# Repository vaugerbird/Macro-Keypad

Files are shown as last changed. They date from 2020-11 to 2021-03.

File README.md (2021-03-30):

# Macro-Keypad
Designed by vaugerbird

Features
---------

* Features 6 programable macro keys
* Controlled by ATMega32u4 that can be flashed with Arduino bootloader
* Uses a USB Type C connector at USB 2.0 speeds
* Updated Pro Micro board is also included (great for beginners)

Notes
------

All of the mechanical key switches are all programed in EAGLE as Cherry MX keys or equivalent footprint

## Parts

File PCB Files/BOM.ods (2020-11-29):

Part Description | Part # | Mouser # | Digikey # | Footprint | $/Unit | Qty # | Board ID # | Mouser Link | Digikey Link | Notes
ATMega32u4 | ATMEGA32U4-MU | 556-ATMEGA32U4-MU | ATMEGA32U4-AURCT-ND | QFN-44 | $3.98 | 1 | N/A | Mouser (https://www.mouser.com/ProductDetail/Microchip-Technology-Atmel/ATMEGA32U4-MU?qs=JV7lzlMm3yJYRpi0cY3cKw%3D%3D) | Digikey (https://www.digikey.com/en/products/detail/microchip-technology/ATMEGA32U4-AUR/2238241) | Had to change from AU to MU to fit PCB
USB C Port | USB4085-GF-A | N/A | 2073-USB4085-GF-ACT-ND | N/A | $1.34 | 1 | USB-C | N/A | Digikey (https://www.digikey.com/en/products/detail/gct/USB4085-GF-A/9859662) | Current footprint incorrect, getting fixed.
5.1k Pull-Down Resistor | CRCW06035K10KKEATR | 71-CRCW06035K10KKEAT | SR0603KR-075K1L-ND | 0603 | $0.37 | 1 | R1 | Mouser (https://www.mouser.com/ProductDetail/Vishay-Dale/CRCW06035K10KKEATR?qs=V3IlGBufnyVplw9ReaVc8A%3D%3D) | Digikey (https://www.digikey.com/en/products/detail/yageo/SR0603KR-075K1L/5948489) | Minimum order of 5000 from Digi
22 Ohm Data Resistor | RS73G2ATTD22R0B | 660-RS73G2ATTD22R0B | 2019-RS73G2ATTD22R0BTR-ND | 0805 | $0.52 | 2 | R2, R3 | Mouser (https://www.mouser.com/ProductDetail/KOA-Speer/RS73G2ATTD22R0B?qs=YwPsRIUVAOdxbc5%2F8NI5WA%3D%3D) | Digikey (https://www.digikey.com/en/products/detail/koa-speer-electronics-inc/RS73G2ATTD22R0B/11573620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) | Minimum order of 5000 from Digi
1uF Capacitor | C0805C105M5PACTU | 80-C0805C105M5P | N/A | 0805 | $0.76 | 1 | C1 | Mouser (https://www.mouser.com/ProductDetail/KEMET/C0805C105M5PACTU?qs=Mv1qlCsH0%252BHK4n8YpZMO7w%3D%3D) | N/A
Push Button Reset Switch | LL3303F065QG | 612-LL3303F065QG | LL3303F065QG-ND | N/A | $0.60 | 1 | RESET | Mouser (https://www.mouser.com/ProductDetail/E-Switch/LL3303F065QG?qs=QtyuwXswaQjocAyEnLyPSg%3D%3D) | Digikey (https://www.digikey.com/en/products/detail/e-switch/LL3303F065QG/4028397) | Minimum order of 7500 from Digi

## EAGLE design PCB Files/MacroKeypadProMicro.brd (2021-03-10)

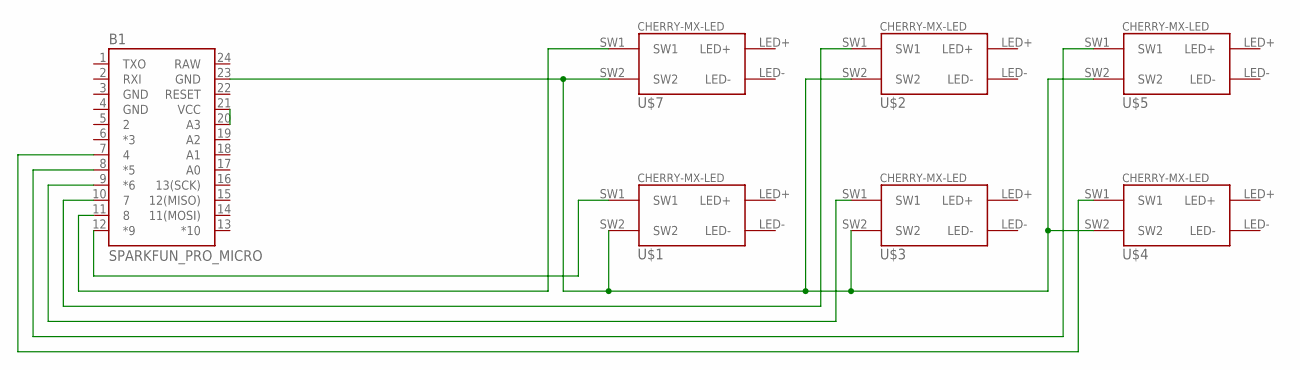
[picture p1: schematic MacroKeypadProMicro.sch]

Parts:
B1: SPARKFUN_PRO_MICRO
U$1, U$2, U$3, U$4, U$5, U$7: CHERRY-MX-LED

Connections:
GND: B1.3 (GND), B1.4 (GND), B1.23 (GND), U$1.SW2, U$2.SW2, U$3.SW2, U$4.SW2, U$5.SW2, U$7.SW2
unnamed: B1.20 (A3), B1.21 (VCC)
RAW: B1.24 (RAW)
SW1: B1.11 (8), U$7.SW1
SW2: B1.9 (*6), U$3.SW1
SW3: B1.7 (4), U$4.SW1
SW4: B1.12 (*9), U$1.SW1
SW5: B1.10 (7), U$2.SW1
SW6: B1.8 (*5), U$5.SW1

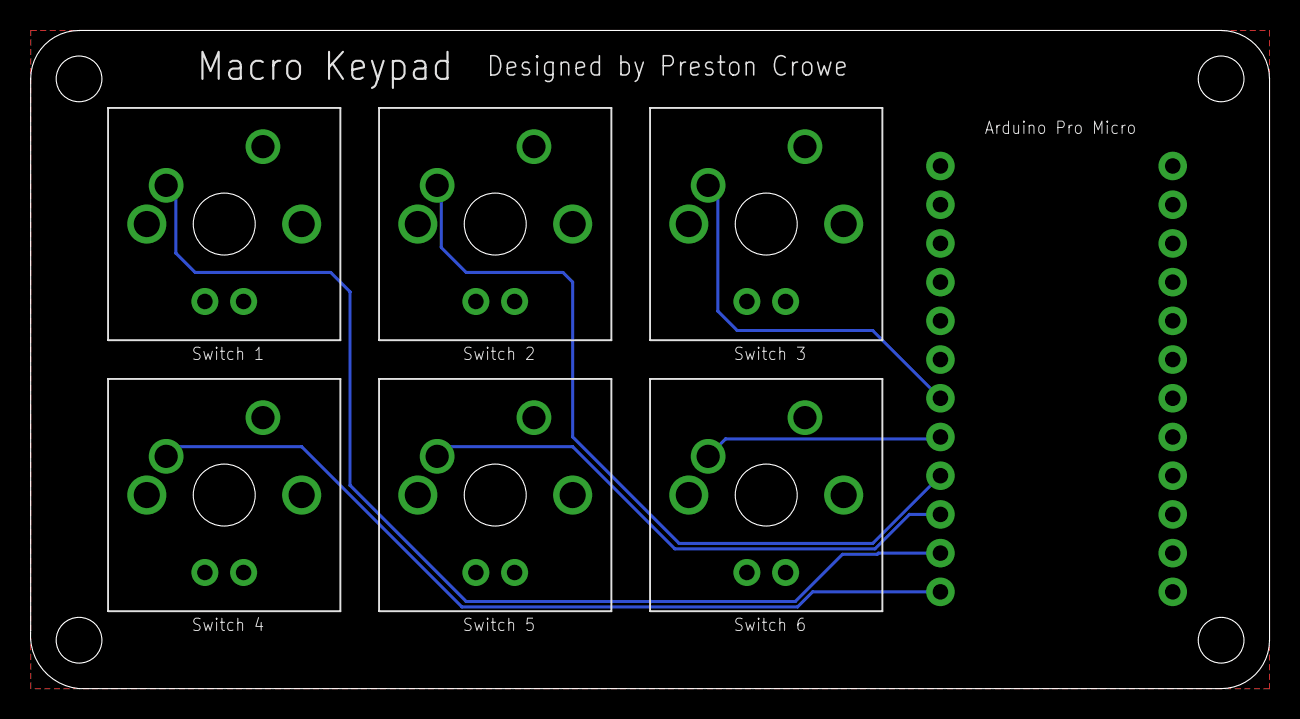
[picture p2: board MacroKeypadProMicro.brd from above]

Board: 2 copper layers, 81.3 x 43.2 mm, 7 parts (0 on the bottom side), 8 nets.

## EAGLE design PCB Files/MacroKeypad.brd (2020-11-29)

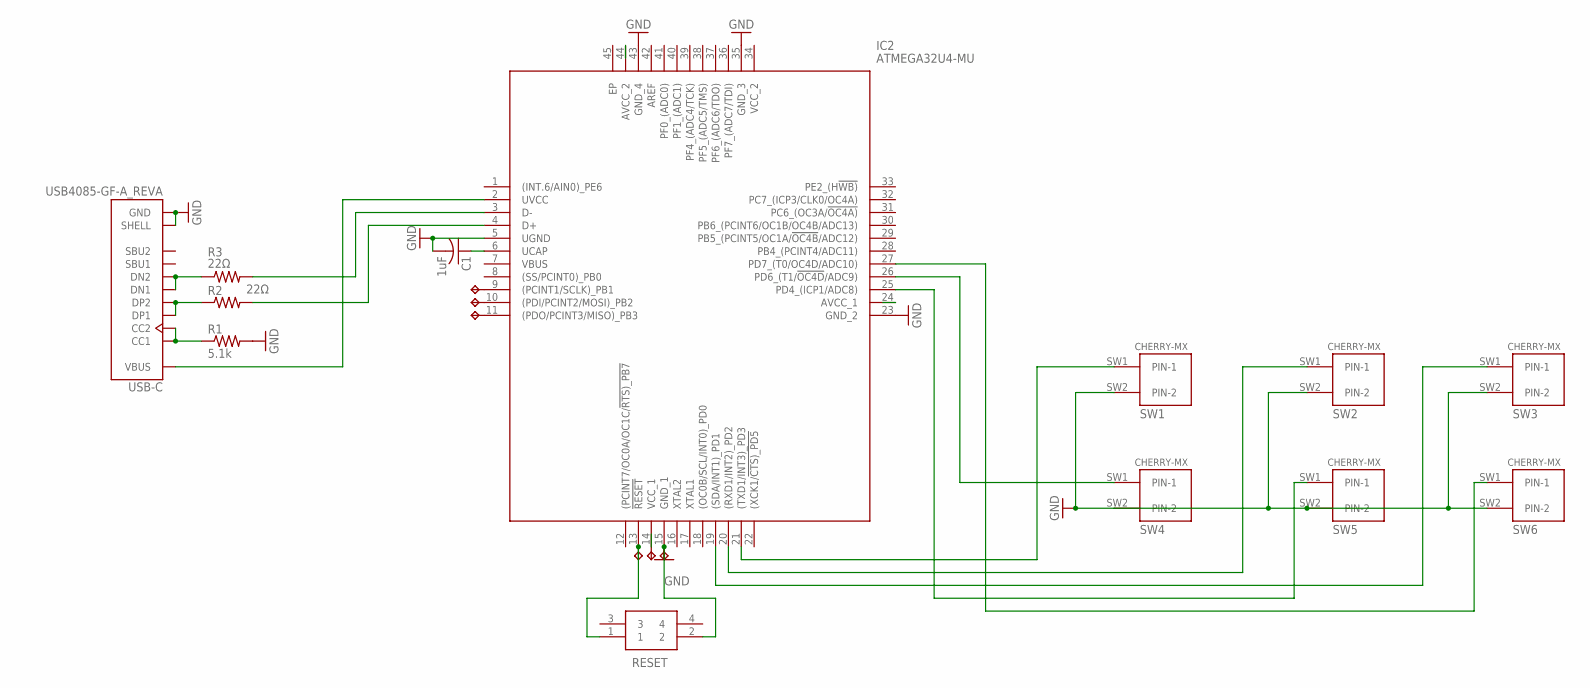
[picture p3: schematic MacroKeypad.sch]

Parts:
5V: TPTP17R; TP17R
C1: 1uF; C0805
GND: TPTP17R; TP17R
IC2: ATMEGA32U4-MU; QFN50P700X700X100-45N
MISO: TPTP17R; TP17R
MOSI: TPTP17R; TP17R
R1: 5.1k; R0603
R2, R3: 22Ω; R0805
RESET: LL3303F065QG
RST: TPTP17R; TP17R
SCLK: TPTP17R; TP17R
SW1, SW2, SW3, SW4, SW5, SW6: CHERRY-MX
USB-C: USB4085-GF-A_REVA; GCT_USB4085-GF-A_REVA

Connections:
CC: R1.1, USB-C.A5 (CC1), USB-C.B5 (CC2)
D+: R2.1, USB-C.A6 (DP1), USB-C.B6 (DP2)
D+RES: IC2.4 (D+), R2.2
D-: R3.1, USB-C.A7 (DN1), USB-C.B7 (DN2)
D-RES: IC2.3 (D-), R3.2
GND: C1.2, GND.TP, IC2.5 (UGND), IC2.15 (GND_1), IC2.23 (GND_2), IC2.35 (GND_3), IC2.43 (GND_4), R1.2, RESET.2, SW1.SW2 (PIN-2), SW2.SW2 (PIN-2), SW3.SW2 (PIN-2), SW4.SW2 (PIN-2), SW5.SW2 (PIN-2), SW6.SW2 (PIN-2), USB-C.A1 (GND), USB-C.A12 (GND), USB-C.B1 (GND), USB-C.B12 (GND), USB-C.P1 (SHELL), USB-C.P2 (SHELL), USB-C.P3 (SHELL), USB-C.P4 (SHELL)
MISO: IC2.11 ((PDO/PCINT3/MISO)_PB3), MISO.TP
MOSI: IC2.10 ((PDI/PCINT2/MOSI)_PB2), MOSI.TP
RESET: IC2.13 (!RESET), RESET.1, RST.TP
SCLK: IC2.9 ((PCINT1/SCLK)_PB1), SCLK.TP
SW1: IC2.21 ((TXD1/INT3)_PD3), SW1.SW1 (PIN-1)
SW2: IC2.20 ((RXD1/INT2)_PD2), SW2.SW1 (PIN-1)
SW3: IC2.19 ((SDA/INT1)_PD1), SW3.SW1 (PIN-1)
SW4: IC2.26 (PD6_(T1/!OC4D!/ADC9)), SW4.SW1 (PIN-1)
SW5: IC2.25 (PD4_(ICP1/ADC8)), SW5.SW1 (PIN-1)
SW6: IC2.27 (PD7_(T0/OC4D/ADC10)), SW6.SW1 (PIN-1)
UCAP: C1.1, IC2.6 (UCAP)
VCC: 5V.TP, IC2.14 (VCC_1), IC2.24 (AVCC_1), IC2.44 (AVCC_2)
VIN: IC2.2 (UVCC), USB-C.A4 (VBUS), USB-C.A9 (VBUS), USB-C.B4 (VBUS), USB-C.B9 (VBUS)

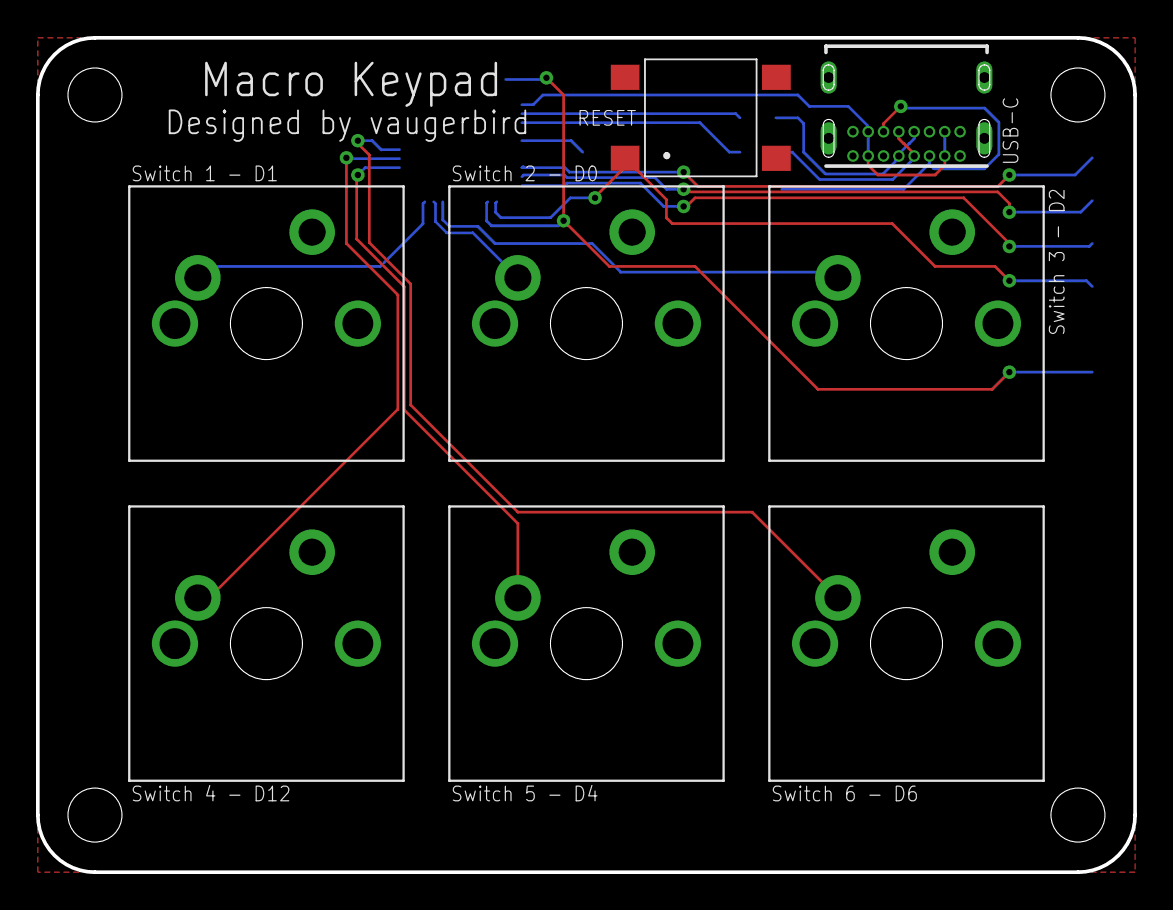
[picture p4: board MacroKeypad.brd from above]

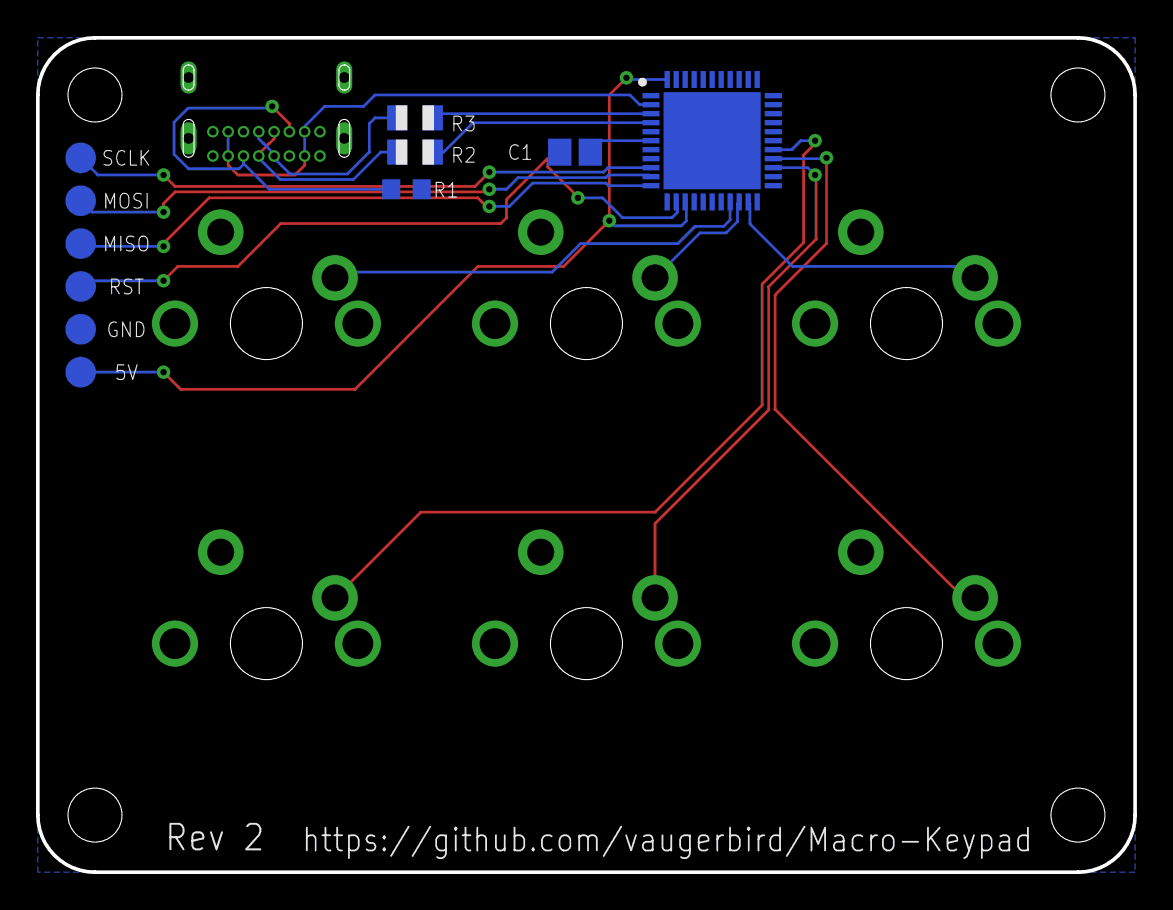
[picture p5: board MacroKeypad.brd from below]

Board: 2 copper layers, 61.0 x 46.4 mm, 19 parts (11 on the bottom side), 19 nets.

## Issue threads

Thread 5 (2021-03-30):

Create Custom Board Definition

vaugerbird, 2021-03-30:
This is very much outside of my current skillset, but I would like to create a custom board definition for the Arduino IDE.

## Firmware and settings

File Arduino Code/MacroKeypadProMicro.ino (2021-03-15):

// Macro Keypad by Preston Crowe 
// Github Repository: https://github.com/PrestonCrowe/Macro-Keypad/

#include <Mouse.h>
#include <Keyboard.h>

// Defining each pin, with a unique name
// S# = Switch #
#define S1 4
#define S2 5
#define S3 6
#define S4 7
#define S5 8
#define S6 9

void setup() {
  // Telling the Arduino that the switches are inputs //
  pinMode (S1, INPUT_PULLUP);
  pinMode (S2, INPUT_PULLUP);
  pinMode (S3, INPUT_PULLUP);
  pinMode (S4, INPUT_PULLUP);
  pinMode (S5, INPUT_PULLUP);
  pinMode (S6, INPUT_PULLUP);

  Keyboard.begin();
  Mouse.begin();
}

void loop() {

    //Switch 2//
    if (digitalRead(S2) == LOW)
    {
      Keyboard.press(KEY_UP_ARROW);
    }
    if (digitalRead(S2) == HIGH)
    {
      Keyboard.release(KEY_UP_ARROW);
    }

    //Switch 5//
    if (digitalRead(S5) == LOW)
    {
      Keyboard.press(KEY_DOWN_ARROW);
    }
    if (digitalRead(S5) == HIGH)
    {
      Keyboard.release(KEY_DOWN_ARROW);
    }

    //Switch 6//
    if (digitalRead(S6) == LOW)
    {
      Keyboard.press(KEY_RIGHT_ARROW);
    }
    if (digitalRead(S6) == HIGH)
    {
      Keyboard.release(KEY_RIGHT_ARROW);
    }

    //Switch 4//
    if (digitalRead(S4) == LOW)
    {
      Keyboard.press(KEY_LEFT_ARROW);
    }
    if (digitalRead(S4) == HIGH)
    {
      Keyboard.release(KEY_LEFT_ARROW);
    }

    //Switch 3//
    if (digitalRead(S3) == LOW)
    {
      Keyboard.press(KEY_LEFT_CTRL);
    }
    if (digitalRead(S3)==HIGH)
    {
      Keyboard.release(KEY_LEFT_CTRL);
    }

    //Switch 1//
    if (digitalRead(S1) == LOW)
    {
      Keyboard.press(KEY_LEFT_ALT);
    }
    if (digitalRead(S1) == HIGH)
    {
      Keyboard.release(KEY_LEFT_ALT);
    }
  }
}

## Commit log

2019-02-19 Re-added files w/ corrected files
    [MacroKeypad-LED-Button.brd, MacroKeypad-LED-Button.sch, MacroKeypad-LED.brd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]
2020-11-25 Clean up old files
    [MacroKeypad-Button.brd, MacroKeypad-Button.sch, MacroKeypad-LED-Button.brd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]
2020-11-26 Brand new PCB started
    Started redesigning PCB and added BOM
    [BOM.ods, MacroKeypad.brd, MacroKeypad.sch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]
2020-11-26 Update more files
    [BOM.ods, MacroKeypad.brd, MacroKeypad.sch]
2020-11-26 (Almost) Finished with the redo
    Pretty much done, just need to fix USB-C port footprint and make code for the new board
    [BOM.ods, MacroKeypad.brd, MacroKeypad.sch]
2020-11-26 Add BOM
    I deleted it before previous push
    [BOM.ods]
2020-11-27 Add programming pads
    Also added the BOM as it was missing
    [BOM.ods, MacroKeypad.brd, MacroKeypad.sch]
2020-11-27 Fix switch 6 and add switch pinout
    [MacroKeypad.brd, MacroKeypad.sch]
2020-11-29 Update MacroKeypad.brd
    Had to change a DRC setting to fix the USB C port. Read up here for more info: https://support.snapeda.com/en/articles/3533844-why-do-pads-overlap-when-adding-to-board-design
    [MacroKeypad.brd]
2020-11-29 Prep for pull
    [BOM.ods]
2020-11-29 Add Gerber files for new PCB
    [BOM.ods, MacroKeypad.brd, MacroKeypad.sch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]
2021-03-10 Finished updated Pro Micro board
    [MacroKeypadProMicro.brd, MacroKeypadProMicro.sch]

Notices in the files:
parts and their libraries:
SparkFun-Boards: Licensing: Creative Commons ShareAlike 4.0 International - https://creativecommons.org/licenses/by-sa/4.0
